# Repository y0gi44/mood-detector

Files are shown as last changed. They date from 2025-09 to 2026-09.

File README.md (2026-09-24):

# Mood Detector

Plateforme de vote sur ESP32 pour recueillir un mood par equipe et consulter
les resultats depuis une interface web locale.

## Demarrage rapide

```bash
$HOME/.platformio/penv/bin/pio run
$HOME/.platformio/penv/bin/pio test -e native
```

Le firmware est genere dans `.pio/build/esp32dev/firmware.bin`.

## Utilisation

1. Alimenter l'ESP32 en USB.
2. Se connecter au Wi-Fi `Mood1` avec le mot de passe configure.
3. Ouvrir `http://192.168.4.1`.
4. Selectionner une equipe sur le clavier, puis appuyer sur `A`, `B` ou `C`.

Le manuel complet est disponible dans [docs/manuel-utilisateur.md](docs/manuel-utilisateur.md).

## Documentation

- [Manuel utilisateur](docs/manuel-utilisateur.md)
- [Schema de cablage](docs/schema-cablage.md)
- [Documentation technique](docs/documentation-technique.md)
- [Documentation materiel](Hardware/Readme.md)
- [Tests](test/README)

## Materiel

- ESP32 Dev Module 30 broches
- RTC DS3231
- clavier matriciel 4x4
- trois LEDs ou boutons lumineux de retour
- alimentation USB 5 V

Le tableau complet des broches et les controles avant mise sous tension sont
dans [docs/schema-cablage.md](docs/schema-cablage.md).

## Securite

Les identifiants du depot sont des valeurs de prototype. Modifier
`include/AppConfig.h` avant toute utilisation partagee. Les serveurs des ports
`80` et `8080` sont proteges par authentification.
# mood-detector

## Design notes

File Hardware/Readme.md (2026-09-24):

# Plateforme de vote

## Prototype
Pour le prototype de la plateforme de vote, il est composé des éléments suivants : 
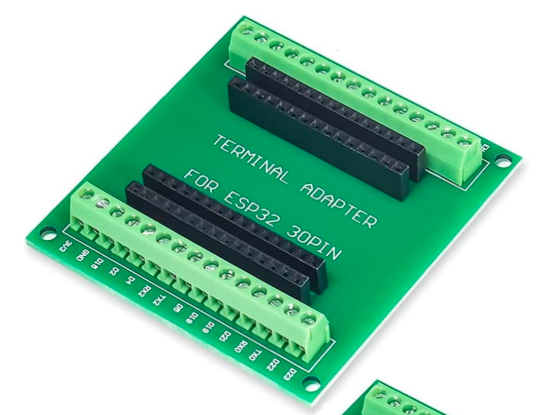
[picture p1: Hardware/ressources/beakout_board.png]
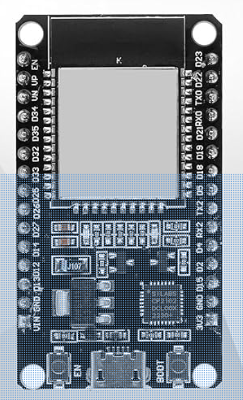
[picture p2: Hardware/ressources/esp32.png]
   * Une [carte pour accueuillir une ESP32 30 pins](https://www.amazon.fr/dp/B0BP7NJ313) + [l'ESP 32](https://www.amazon.fr/dp/B0D86JL12Q)  + 

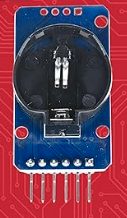
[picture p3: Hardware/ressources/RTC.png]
   * [Horloge RTC](https://www.amazon.fr/dp/B077XN4LL4) 
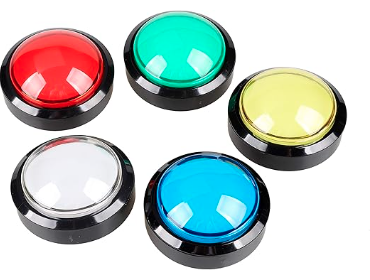
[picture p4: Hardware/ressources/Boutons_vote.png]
   * Pour le choix du moral : [3 Gros boutons lumineux de 60mm de diamètre](https://www.amazon.fr/dp/B01MSNXLN0) 
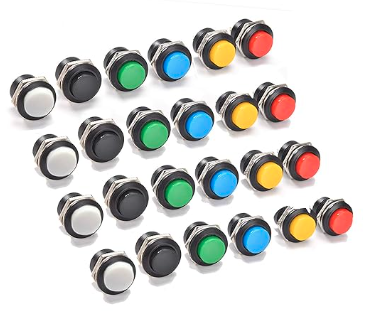
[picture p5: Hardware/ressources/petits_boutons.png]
   * Pour le choix de l'équipe : [9 petits boutons](https://www.amazon.fr/dp/B09MBQSM44) 
   * [Plaques perforées pour prototypage](https://www.amazon.fr/dp/B076TD3LMG) pour faire la carte du clavier matriciel.
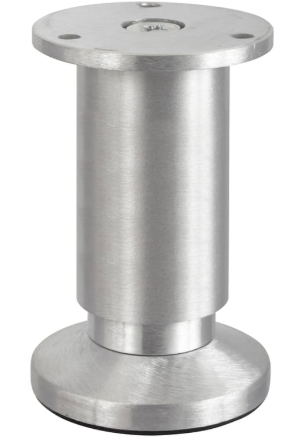
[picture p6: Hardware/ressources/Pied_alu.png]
   * Des pieds Leroy merlin qui trainait par là :-p [Pieds e, alu brossé] (https://www.leroymerlin.fr/produits/pied-de-meuble-cime-brosse-diametre-3-8-cm-x-hauteur-reglable-de-10-a-12-cm-69154841.html)
   * Une plaque de bois de 27 x 50 cm (recyclage d'une chute de parquet ^^)

Coté petit matériel et outils :
    * mon fidèle fer à souder
    * de l'étain
    * des cosses
    * une pinces à sertir
    * des connecteur dupont
    * des fils

Et voila :-)
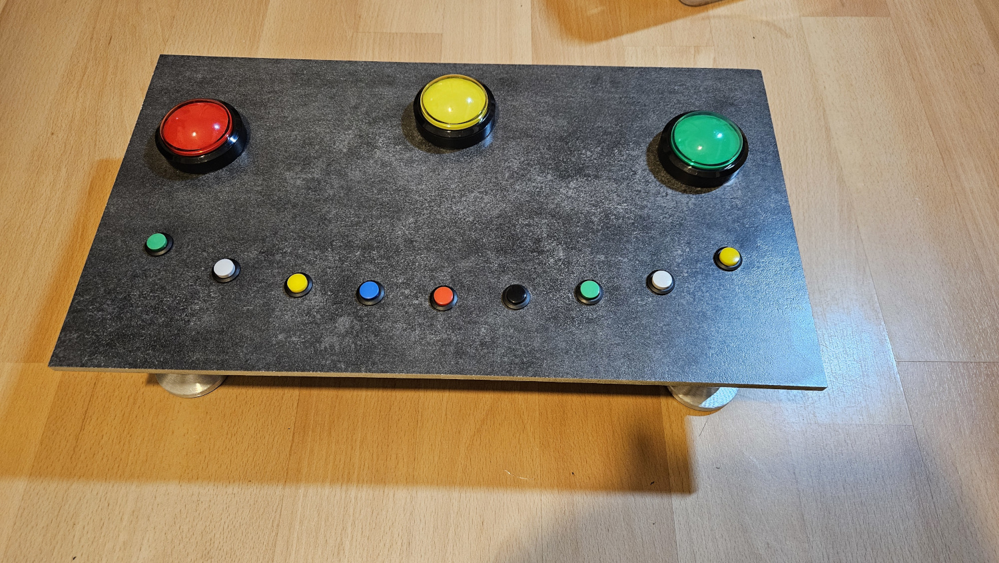
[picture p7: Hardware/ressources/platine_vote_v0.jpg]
 

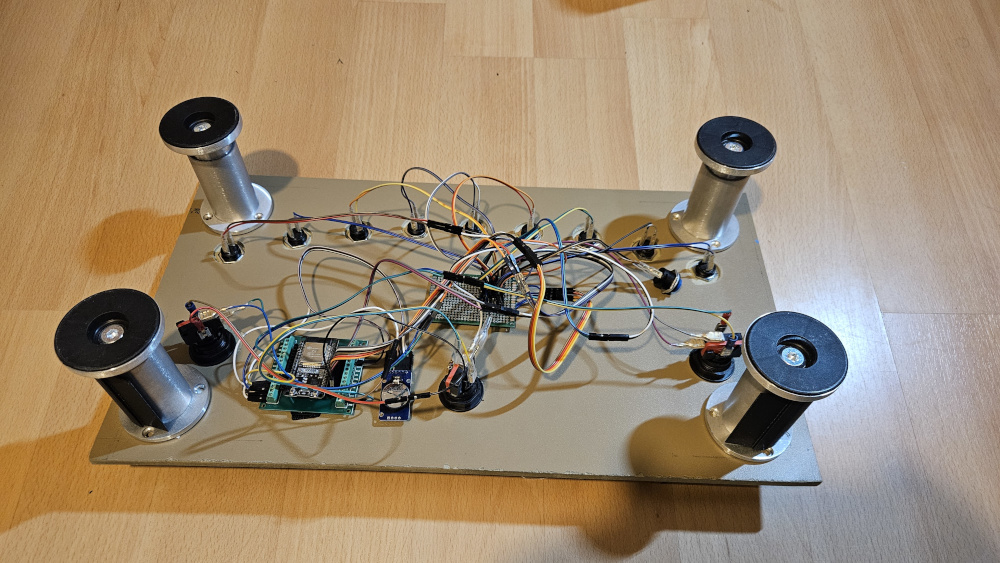
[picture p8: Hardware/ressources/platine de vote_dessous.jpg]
 

## La version portable

Par contre pour travailler dessus, la platine complète est un peu encombrante.
J'ai créé une seconde version plus portable qui tiens dans un petit tuperware avec un clavier matriciel 4x4 (https://www.amazon.fr/dp/B07CNXPZS4)

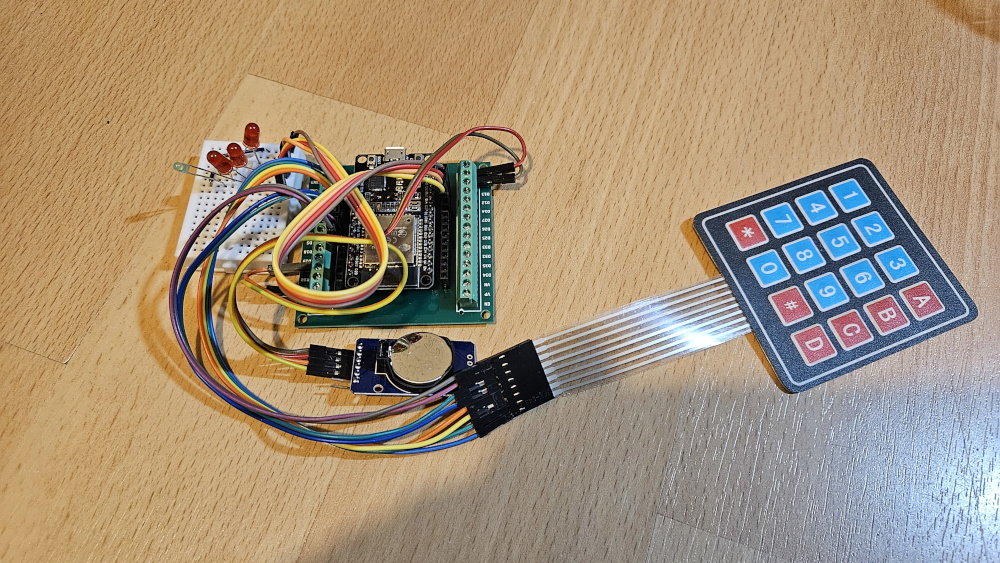
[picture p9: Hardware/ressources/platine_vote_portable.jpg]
 

## Un peu d'impression 3D

Afin de fermer un peu la vue de tous les fils, j'ai modélisé en 3D rapidement des pièces pour venir fermer un peu la vue.

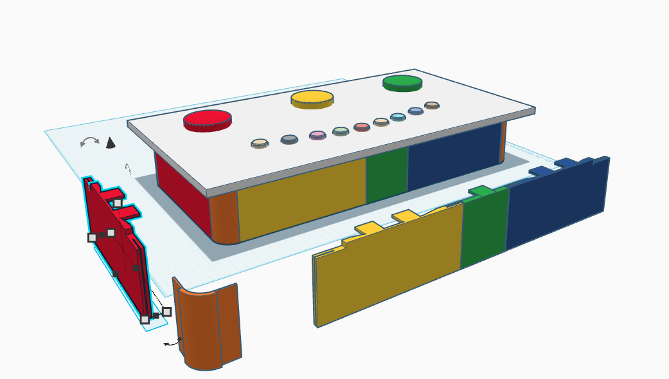
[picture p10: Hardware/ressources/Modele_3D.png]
 

J'ai mis dans le répertoir STL les modèles 3D des différentes pieces

## Documentation technique actuelle

Le firmware actif cree le point d'acces Wi-Fi `Mood1` et expose la page
principale sur `http://192.168.4.1`. Le detail des broches, du clavier et du
RTC est maintenu dans [../docs/schema-cablage.md](../docs/schema-cablage.md).

Le manuel de connexion et d'utilisation est dans
[../docs/manuel-utilisateur.md](../docs/manuel-utilisateur.md).

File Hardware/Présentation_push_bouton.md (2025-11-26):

# Push Bouton - Système de Vote pour Estimation du Nombre de Convives au restaurant d'entreprise

## Problématique

Le **RIE (Restaurant d'entreprise)** nécessite une estimation du nombre de convives pour optimiser la préparation des repas et l'organisation logistique. 

## But du Projet

Développer une **platine de vote électronique** permettant de comptabiliser automatiquement le nombre de convives souhaitant déjeuner au RIE, offrant ainsi une solution moderne et efficace pour l'estimation des participants.

## Vue d'ensemble de la Platine

### Caractéristiques Principales
- Système de vote intuitif et accessible
- Consultation des statistique via interface web
- La borne met à disposition son propre point d'accès wifi sécurisé
- Alimentation par USB pour une utilisation flexible
- Boîtier compact et portable

## Photos du Système

- Vue d'ensemble de la platine

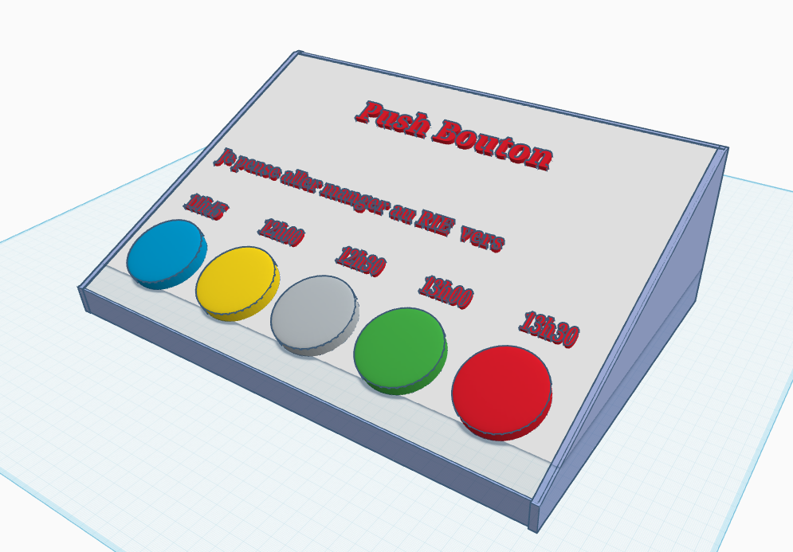
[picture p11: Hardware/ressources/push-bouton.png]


- Vue de la platine adapté sur un autre usage



- Interface utilisateur

- Composants internes

[l'ESP 32](https://www.amazon.fr/dp/B0D86JL12Q) 
</br>

[Une Horloge RTC](https://www.amazon.fr/dp/B077XN4LL4) 
</br>

Les boutons : [Gros boutons lumineux de 60mm de diamètre](https://www.amazon.fr/dp/B01MSNXLN0) 
</br>

## Shema Electrique : 

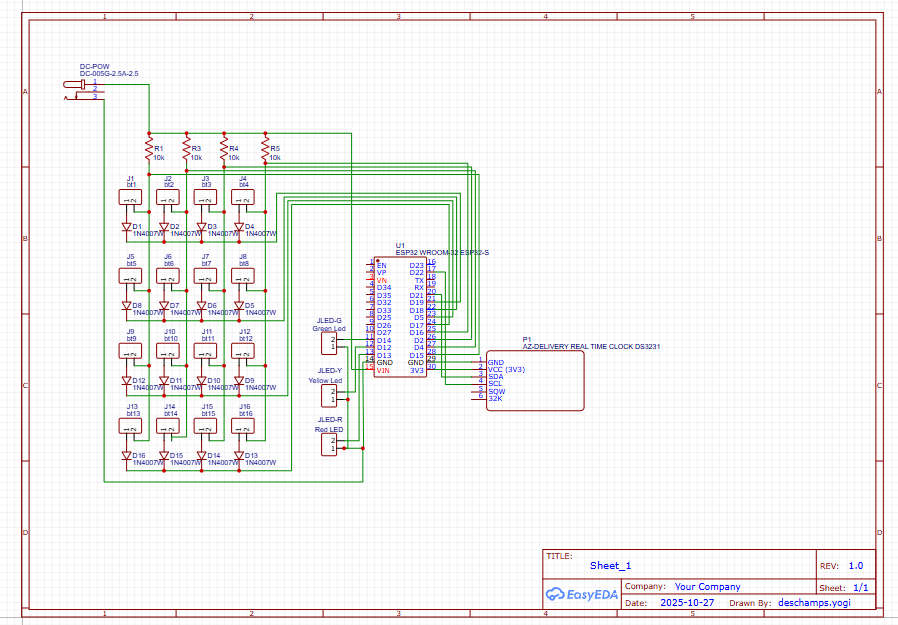
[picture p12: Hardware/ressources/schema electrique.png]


## Dimensions et Poids

- **Dimensions** : 406 mm x 276 mm x 133 mm
- **Poids** : < 2000 grammes
- **Format** : Portable et facilement transportable

## Liste des Composants

### Composants Principaux
- **Microcontrôleur** : ESP32 (WiFi + Bluetooth intégré)
- **Alimentation** : Chargeur téléphone USB ou prise avec port USB aux normes NF / CE
- **Boîtier** : Bois/Plexi/Impression 3D, à définir en fonction des contraintes

### Composants Additionnels
- LED d'indication de statut
- Boutons de selection

## Alimentation

### Caractéristiques Électriques
- **Tension d'entrée** : 5V DC via USB
- **Tension de fonctionnement** : 3.3V (régulée en interne)
- **Puissance consommée** : 
  - Mode actif WiFi : ~240 mA
  - Mode veille : ~10 µA
  - Puissance totale : ~1.2W en fonctionnement normal

### Sources d'Alimentation
- Chargeur de téléphone standard (5V/1A minimum)
- Port USB d'ordinateur
- Batterie externe USB (power bank)
- Adaptateur secteur USB

## Spécifications WiFi

### ESP32 - Caractéristiques Radio
- **Standard** : IEEE 802.11 b/g/n (WiFi 4)
- **Fréquence** : 2.4 GHz
- **Puissance d'émission** : 
  - Maximum : +20 dBm
  - Typique : +18 dBm
- **Portée** : Jusqu'à 150m en champ libre
- **Modes supportés** : 
  - Station (STA)
  - Point d'accès (AP)
  - Station + Point d'accès simultané

## Interface Homme-Machine (IHM)

### Accès au Système
- **Mode de connexion** : Hotspot WiFi intégré
- **SSID** : "MoodDetector-Vote"
- **URL d'accès** : `http://192.168.4.1` ou `http://mood-detector.local`
- **Interface** : Page web compatible mobile/desktop

### Fonctionnalités de l'Interface
- Comptage simple, possibilité d'évoluer et de comptabiliser par créneau horaire
- Consultation des résultats en temps réel sur l'interface web
- Export des données au format csv

## Code Source

Le code source complet du projet est disponible sur GitHub :

**🔗 [https://github.com/y0gi44/mood-detector](https://github.com/y0gi44/mood-detector)**

### Structure du Repository
- `/Hardware` : Schémas électroniques et fichiers de conception
- `/Software` : Code ESP32 (Arduino IDE/PlatformIO)
- `/Web` : Interface utilisateur (HTML/CSS/JavaScript)
- `/Documentation` : Guides d'utilisation et documentation technique

---

## Installation et Utilisation

### Mise en Route
1. Connecter l'alimentation USB
2. Attendre l'initialisation (LED de statut)
3. Se connecter au réseau WiFi "MoodDetector-Vote"
4. Accéder à l'interface via navigateur web
5. Commencer le vote

### Support Technique
Pour toute question ou problème, consulter la documentation sur GitHub ou créer une issue sur le repository du projet.

---

*Projet développé pour estimer le nombre de convives au Restaurant d'entreprise - RIE 2025*

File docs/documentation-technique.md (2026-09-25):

# Documentation technique

## Architecture

```text
src/main.cpp
    |
    +-- Mood
         +-- Votes / VoteItem       Comptage et persistance des votes
         +-- Keyboard               Lecture du clavier matriciel
         +-- Affichage               Sequences LED non bloquantes
         +-- RTC DS3231              Date et heure
         +-- WiFiServer:80            Interface web et CSV
         +-- WebServer:8080           Sauvegarde, restauration et OTA
         +-- Preferences             Persistance flash ESP32
```

`Mood` est l'application active. La variante historique `Creneau` reste dans le depot mais est exclue du build courant par `lib_ignore = Creneau`.

## Build

```bash
$HOME/.platformio/penv/bin/pio run
```

Le binaire est genere dans :

```text
.pio/build/esp32dev/firmware.bin
```

## Tests

Les tests de logique de vote sont independants du materiel :

```bash
$HOME/.platformio/penv/bin/pio test -e native
```

Ils verifient :

- les moods 1, 2 et 3 ;
- les bornes de candidats ;
- la serialisation et la restauration ;
- le rejet de donnees invalides.

## Configuration

Les valeurs de prototype sont centralisees dans `include/AppConfig.h` :

- SSID du point d'acces ;
- mot de passe Wi-Fi ;
- utilisateur OTA ;
- mot de passe OTA.

Modifier ce fichier avant toute installation partagee.

## Contrats de donnees

Un element de vote est serialise sous la forme :

```text
mood1;mood2;mood3;
```

La collection est serialisee avec `|` entre les candidats :

```text
mood1;mood2;mood3;|mood1;mood2;mood3;|
```

Les compteurs sont des `uint16_t` et sont satures a `65535`. Les donnees invalides sont ignorees et l'element concerne est remis a zero.

## Cycle principal

La boucle Arduino execute successivement :

1. lecture d'une requete HTTP brute ;
2. lecture du clavier ;
3. traitement d'un vote ;
4. progression d'une animation LED ;
5. traitement du serveur OTA.

Le serveur HTTP brut dispose d'un timeout d'inactivite de deux secondes et limite la taille des en-tetes a 1024 octets.

## Ports reseau

| Port | Service | Authentification |
|---:|---|---|
| 80 | page web, date, resultats, CSV, reset (avec confirmation) | Basic Auth |
| 8080 | sauvegarde, restauration, reset, OTA | Basic Auth |

## Points de vigilance

- Les deux serveurs HTTP demandent les identifiants de `include/AppConfig.h`.
- Les identifiants sont stockes dans le firmware et doivent etre changes avant production.
- L'ESP32 doit etre alimente en 3.3 V sur ses GPIO.
- Une validation sur materiel reel reste necessaire pour les timings du clavier, les LEDs et le RTC.

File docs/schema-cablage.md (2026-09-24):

# Schema de cablage

Ce document decrit le cablage correspondant au firmware `Mood` actif.

## Vue fonctionnelle

```mermaid
flowchart LR
    USB[Alimentation USB 5 V] --> ESP[ESP32 Dev Module]
    RTC[RTC DS3231] -->|I2C SDA 21 / SCL 22| ESP
    ESP -->|GPIO 19 18 5 17| ROWS[Lignes clavier 4x4]
    ESP -->|GPIO 16 4 2 15| COLS[Colonnes clavier 4x4]
    ESP -->|GPIO 14| GREEN[LED verte]
    ESP -->|GPIO 12| YELLOW[LED jaune]
    ESP -->|GPIO 13| RED[LED rouge]
```

## Alimentation et masse

| Element | VCC | GND | Remarque |
|---|---:|---:|---|
| ESP32 | USB 5 V | GND | Utiliser une alimentation stable de 5 V / 1 A minimum |
| RTC DS3231 | 3.3 V | GND | Ne pas appliquer 5 V sur une entree GPIO |
| Clavier 4x4 | 3.3 V si necessaire | GND commun | Les 8 lignes sont lues par la bibliotheque Keypad |
| LEDs | GPIO via resistance | GND commun | Prevoir une resistance serie par LED |

## RTC DS3231

| DS3231 | ESP32 |
|---|---:|
| SDA | GPIO 21 |
| SCL | GPIO 22 |
| VCC | 3V3 |
| GND | GND |

Le firmware utilise `RTC_DS3231` et initialise l'heure avec la date de compilation si le module signale une perte d'alimentation.

## LEDs de retour utilisateur

| Fonction | Couleur | GPIO firmware |
|---|---|---:|
| Mood 1 | Vert | 14 |
| Mood 2 | Jaune | 12 |
| Mood 3 | Rouge | 13 |

Le GPIO ne doit pas alimenter directement une charge importante. Pour un gros bouton lumineux ou une lampe, utiliser un transistor ou un module de commande adapte.

## Clavier matriciel 4x4

Le tableau de touches defini dans `lib/Keyboard/Keyboard.cpp` est :

```text
Ligne 0 : 6  5  D  A
Ligne 1 : 7  4  ;  B
Ligne 2 : 8  3  2  C
Ligne 3 : 9  1  #  *
```

### Broches

| Groupe | GPIO |
|---|---|
| Lignes | 19, 18, 5, 17 |
| Colonnes | 16, 4, 2, 15 |

Les boutons de vote utilisent `A`, `B` et `C`. Les touches numeriques selectionnent les equipes dans la logique `Mood`.

## Regles de cablage

- relier toutes les masses ensemble ;
- garder les fils I2C courts autant que possible ;
- ne pas utiliser un GPIO deja affecte a une autre fonction ;
- verifier le brochage reel de la carte ESP32 30 broches avant soudure ;
- tester chaque GPIO avec une mesure de continuite avant la mise sous tension.

## Verification avant mise sous tension

1. Verifier l'absence de court-circuit entre 3V3 et GND.
2. Verifier le sens SDA/SCL.
3. Verifier les resistances serie des LEDs.
4. Verifier que les boutons ne renvoient pas 5 V vers l'ESP32.
5. Alimenter d'abord par USB avec les LEDs de puissance debranchees si le montage est nouveau.

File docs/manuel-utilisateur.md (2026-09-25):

# Manuel utilisateur

## 1. Demarrage

1. Brancher l'ESP32 sur une alimentation USB 5 V.
2. Attendre la sequence de demarrage des LEDs.
3. Depuis un telephone ou un ordinateur, ouvrir la liste des reseaux Wi-Fi.
4. Se connecter au point d'acces :

   - SSID : `Mood1`
   - Mot de passe : `123456789`

5. Ouvrir `http://192.168.4.1` dans un navigateur et saisir les identifiants :
   - utilisateur : `admin` ;
   - mot de passe : `123456789`.

L'adresse IP est affichee sur le port serie au demarrage. Le nom `mood-detector.local` n'est pas configure par le firmware actuel et ne doit donc pas etre utilise comme adresse de reference.

## 2. Enregistrer un vote

Sur la borne :

1. Selectionner une equipe avec une touche numerique.
2. Appuyer sur un bouton de mood :
   - `A` : mood 1, affiche en vert dans la version `Mood` actuelle ;
   - `B` : mood 2, affiche en jaune ;
   - `C` : mood 3, affiche en rouge.
3. La LED confirme la prise en compte du vote.

Dans la version `Mood`, les touches numeriques `1` a `9` selectionnent les equipes correspondantes. Le clavier matriciel ne possede pas de touche `0` dediee : l'equipe 0 n'a pas de touche physique explicite dans la configuration actuelle.

Un mood appuye sans equipe selectionnee est refuse et declenche la sequence d'erreur.

## 3. Consulter les resultats

Depuis `http://192.168.4.1` :

- la date et l'heure du RTC sont affichees ;
- la duree depuis le demarrage est affichee ;
- le tableau des votes affiche les trois moods par equipe ;
- les totaux sont affiches en bas du tableau ;
- le lien de telechargement exporte un CSV.

Le serveur principal utilise le port HTTP `80`.

## 4. Sauvegarder et restaurer

Les actions de sauvegarde et de restauration sont aussi disponibles sur le serveur OTA :

- `http://192.168.4.1:8080/save`
- `http://192.168.4.1:8080/restore`
- `http://192.168.4.1:8080/reset`
- `http://192.168.4.1:8080/download`

Identifiants actuels :

- utilisateur : `admin`
- mot de passe : `123456789`

`reset` efface la sauvegarde et remet aussi les votes en memoire a zero. Les votes sauvegardes sont automatiquement restaures au redemarrage.

Le bouton "Reinitialiser" de la page principale (`http://192.168.4.1/reset`) mene a une page de confirmation avant d'effacer les votes, pour eviter un reset accidentel.

## 5. Regler l'heure

Sur la page principale, utiliser le formulaire avec le format strict :

```text
YYYYMMDDHHMMSS
```

Exemple : `20260924143000`.

Une date invalide est refusee avec une reponse HTTP `400`.

## 6. Mise a jour OTA

1. Se connecter au Wi-Fi `Mood1`.
2. Ouvrir `http://192.168.4.1:8080/update`.
3. S'authentifier avec les identifiants OTA.
4. Televerser le firmware genere par PlatformIO.

Le fichier attendu est generalement :

```text
.pio/build/esp32dev/firmware.bin
```

Ne pas couper l'alimentation pendant la mise a jour.

## 7. Depannage

### Le reseau Wi-Fi n'apparait pas

- verifier l'alimentation USB ;
- redemarrer l'ESP32 ;
- verifier le port serie a `115200` bauds.

### La page ne repond pas

- verifier que l'appareil est connecte a `Mood1` ;
- utiliser `http://192.168.4.1`, sans HTTPS ;
- verifier que le port `80` n'est pas remplace par `8080`.

### Les votes ne sont pas conserves

- utiliser `/save` avant de couper l'alimentation ;
- verifier que `Preferences` s'ouvre correctement dans le port serie ;
- utiliser `/restore` pour recharger explicitement la sauvegarde.

## 8. Securite

Les identifiants actuels sont des valeurs de prototype. Avant une utilisation reelle :

- modifier les valeurs dans `include/AppConfig.h` ;
- ne pas partager le mot de passe ;
- ne pas exposer le point d'acces a un reseau non controle ;
- le serveur principal et le serveur OTA utilisent tous les deux Basic Auth ;
   modifier les identifiants avant une utilisation reelle.

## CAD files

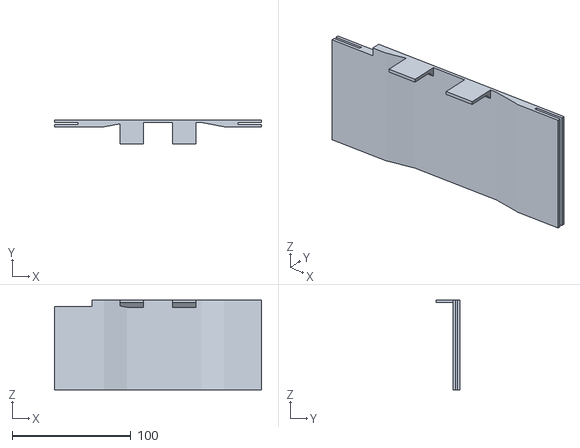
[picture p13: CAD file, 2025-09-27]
Hardware/STL/face_gauche.stl
174.0 x 20.0 x 75.4

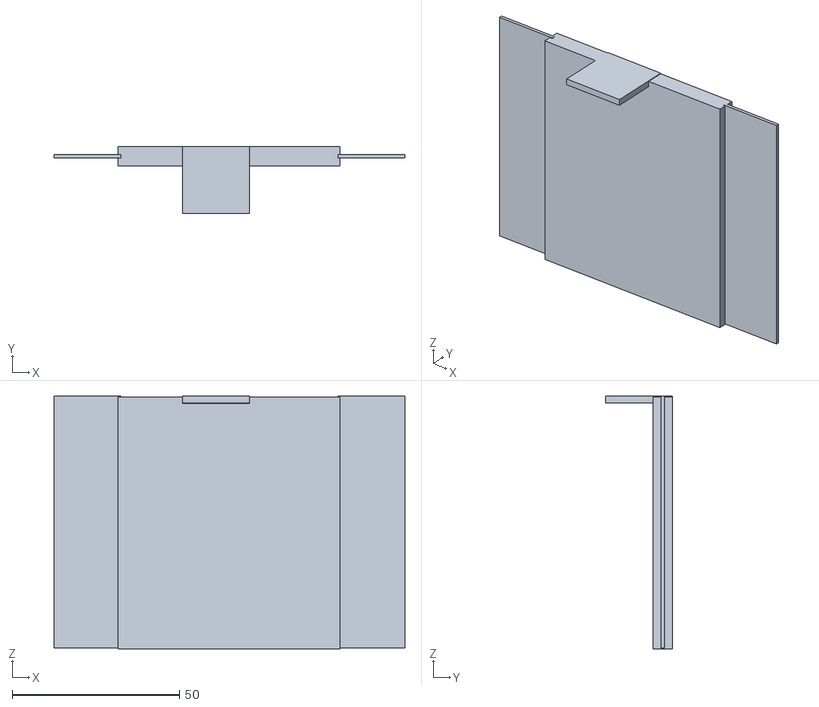
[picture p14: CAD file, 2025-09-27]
Hardware/STL/face_milieu.stl
105.0 x 20.0 x 75.6

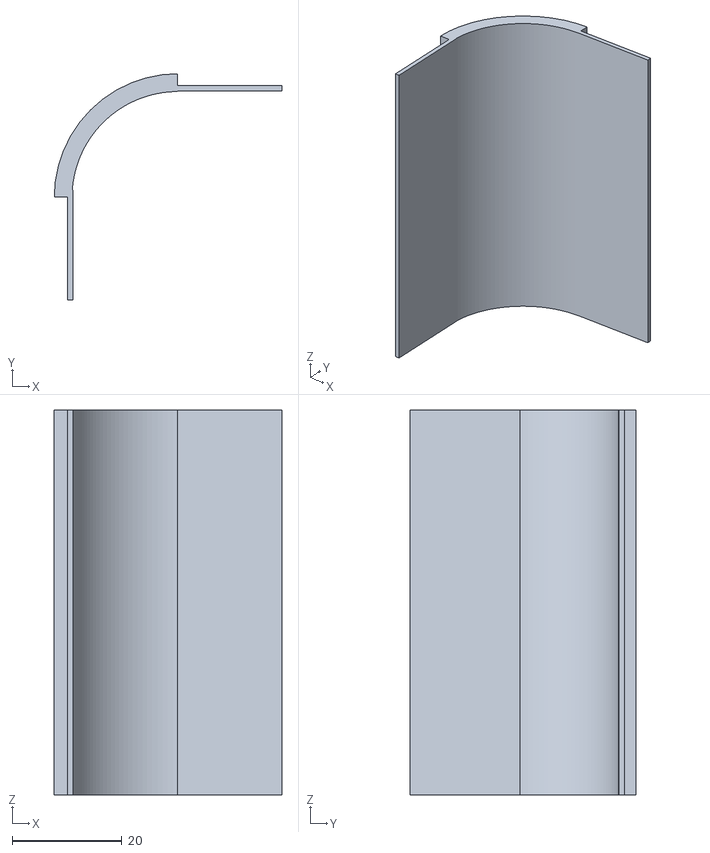
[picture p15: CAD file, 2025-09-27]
Hardware/STL/angle.stl
41.4 x 41.2 x 70.0

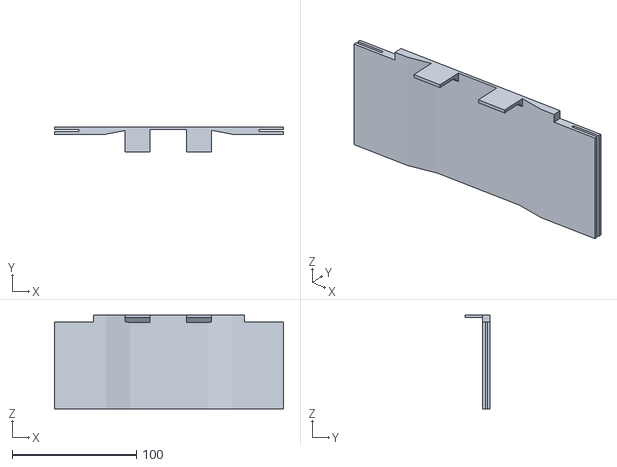
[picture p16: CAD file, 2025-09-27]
Hardware/STL/coté.stl
184.5 x 20.0 x 75.4

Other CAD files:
Hardware/STL/face_droite.stl

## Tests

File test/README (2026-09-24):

This directory is intended for PlatformIO Test Runner and project tests.

Unit Testing is a software testing method by which individual units of
source code, sets of one or more MCU program modules together with associated
control data, usage procedures, and operating procedures, are tested to
determine whether they are fit for use. Unit testing finds problems early
in the development cycle.

More information about PlatformIO Unit Testing:
- https://docs.platformio.org/en/latest/advanced/unit-testing/index.html

## Lancer les tests

Les tests de logique de vote fonctionnent sur la machine hote et ne necessitent
pas d'ESP32 :

```bash
pio test -e native
```

Ils couvrent l'indexation des moods, les bornes des candidats, la
serialisation/restauration et le rejet de donnees invalides.

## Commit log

2025-06-18 Mise en place de l'OTA pour pouvoir laisser le hardware sur site
2025-06-18 Ajout de l'équipe 9
2025-06-25 Sortir le clavier + l'affichage pour qu'il soit non bloquant
2025-07-09 Ajout de la fonctionnalité
2025-07-15 Ajout du mode creneau de rie
2025-07-15 ajout de la réinit de l'affichage lors du lancement d'une nouvelle sequence quand le première est encore en cours
2025-09-20 Amélioration de la page web + correction pb de http1.1 qui conserve la connexion ouverte et bloque la plateforme de vote + ajout des totaux sur la derniere ligne
2025-09-27 Ajout du readme et des modèles 3D
    [angle.stl, coté.stl, face_droite.stl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]
2025-11-26 push de la doc pour la plateforme de RIE
2026-09-24 Ajout de protection par mdp + refonte IHM
